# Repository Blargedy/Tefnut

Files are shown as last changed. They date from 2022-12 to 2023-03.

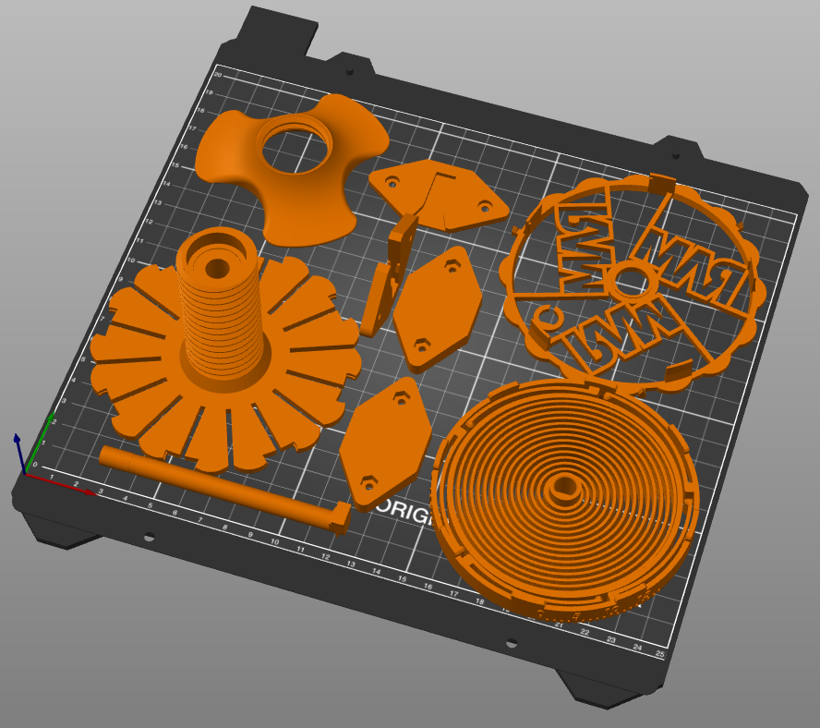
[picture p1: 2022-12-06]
Individual-Spool_Dry-box_Inserts_and_Modified_Universal_Auto-Rewind_Spool_Holder/images/ExampleLayoutOfRequiredParts.png

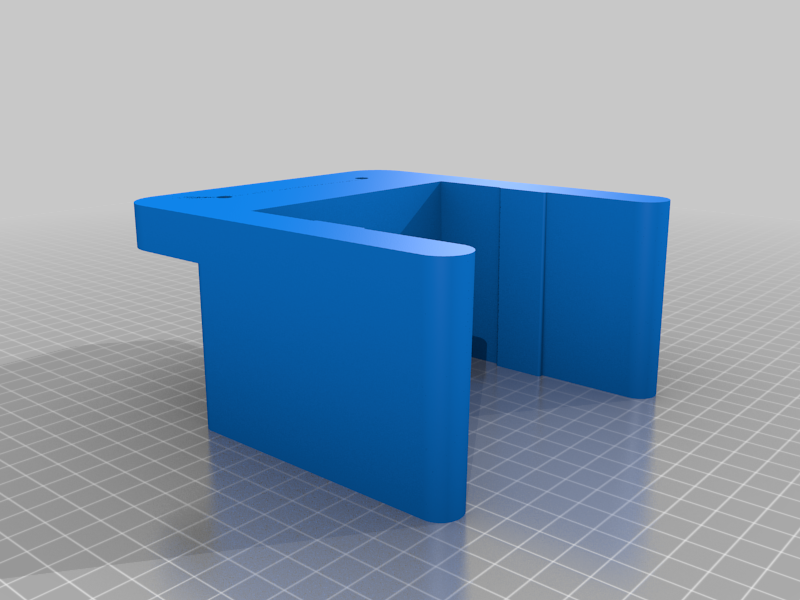
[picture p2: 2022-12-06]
Drybox_Holder_for_Rubbermaid_1861476_Zylar_Container/images/DryboxHolder_SlideDown_v1.2.png

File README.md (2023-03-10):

# Tefnut Filament Handling
A system for the management of 3D printer filament. Based on cereal containers as individual dryboxes for spools of filament.

## Goal
The primary purpose of Tefnut is to keep filament clean of dust/debris to avoid jams and clogs, and can also help with keeping filament dry. I found there is too much air leakage in the system to maintain a low humidity long term without regular swapping of large amounts of dessecant. That being said, with regular swapping of large amounts of dessecant it is possible to keep each filament completely dry. 

## [Individual-Spool Dry-box Inserts and Modified Universal Auto-Rewind Spool Holder](https://github.com/Blargedy/Tefnut_Filament_Handling/tree/main/Individual-Spool_Dry-box_Inserts_and_Modified_Universal_Auto-Rewind_Spool_Holder)

This set of modifications and new custom parts moves [VincentGroenhuis'](https://www.thingiverse.com/thing:3338467) rewinder into a Rubbermaid 1776473 21-Cup Dry Food Container. When combined with a panel mounted pneumatic fitment or mmu tube holder you can print directly from this dry-box.

## [The Filament Butler - a manual replacement of the prusa MMU2s](https://github.com/Blargedy/The_Filament_Butler)
cropped_20221014_140138
For use in high(ish) temperature printing, where the Prusa MMU2s electronics cannot function, this butler keeps the filaments handy for loading, all without needing to open the dryboxes. See the github site for The Filament Butler for instructions and files.

## [Drybox Holder for Rubbermaid 1861476 Zylar Container](https://github.com/Blargedy/Tefnut_Filament_Handling/tree/main/Drybox_Holder_for_Rubbermaid_1861476_Zylar_Container)

This slide-down box-holder keeps the dry-boxes in place during lid-lifting maintenance. 

## [6mm OD tubing to MMU2 adapter](https://github.com/Blargedy/Tefnut_Filament_Handling/tree/main/6mm_OD_Tubing_to_MMU_Adapter)

A similar push-to-connect interface for 6mm tubing as the pneumatic fitment tube holders, for connected the tubing to the MMU2.

## [Push-Fit Tube Holders For 6mm Outer Diameter Tubing](https://github.com/Blargedy/Tefnut_Filament_Handling/tree/main/Push-Fit_Tube_Holders_For_6mm_Outer_Diameter_Tubing)

A two-part mod; An attachment point for 6mm OD tubing on the outside, and a funnel guide for filament being pulled from spools that are almost out of filament on the inside.

## [Enclosure Lid Safety-Harness](https://github.com/Blargedy/Tefnut_Filament_Handling/tree/main/Enclosure_Lid_Safety-Harness)

An anchor point for the lid intended for a 2mm twisted steel cable to loop through and create an over-lifting protection.

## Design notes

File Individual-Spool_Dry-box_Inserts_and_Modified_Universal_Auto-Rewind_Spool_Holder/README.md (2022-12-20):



Need to move your spool of filament into a dry-box while still using the Universal Auto-Rewind Spool Holder? This set of files will let you do so. This set of modifications and new custom parts moves VincentGroenhuis' rewinder into a [Rubbermaid 1776473 21-Cup Dry Food Container](https://www.amazon.ca/Rubbermaid-1776473-21-Cup-Food-Container/dp/B003EYUZJU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). When combined with a panel mounted pneumatic fitment or mmu tube holder you can print directly from this dry-box. Use this [better axle](https://www.thingiverse.com/thing:4324181) remix made by [itnaanti](https://www.thingiverse.com/itnaanti/designs).

For keeping a set of dry-boxes on top of the [mmu compatible printing enclosure](https://blog.prusaprinters.org/mmu2s-printer-enclosure/) see the [dry-box holder](https://github.com/Blargedy/Tefnut/tree/main/Drybox_Holder_for_Rubbermaid_1861476_Zylar_Container), specifically designed for the Rubbermaid container used. Five of these holders are required, as well as 470 cm of new longer and wider tubing. The new tubing is 4mm inner diameter (ID) and 6mm outer diameter (OD), from now on called 4 ID/6 OD tubing.The lengths to cut are:

* 4x 90 cm
* 1x 110 cm

If you value symmetry over minimum tubing length you can use a 3-in-the-front-2-in-the-back pattern and cut a 90 cm piece to 110 cm instead. This will give a total tube length of 480 cm. 

### NB: due to the increased length of tubing required to use these containers on top of the printer enclosure, using the same 2 ID/4 OD tubing the mmu came with, but cut longer, will not work. The friction introduced is too high and will cause frequent jams, especially during filament unloads. 

This is due to the slight deformation of the filament by the bondtech gear during unload being too much if there is already friction from 90cm of tubing. Previously I used very short lengths of 4 ID/6 OD tubing, but the reverse torque of the rewinders pulled the filament out of ready-to-load position. Now however the 90cm of tubing is enough friction to prevent the rewinder pulling the filament out, but low enough to feed beautifully. I've had no load/unload issues since switching to the high diameter tubing. 

In order to use 4 ID/6 OD tubing you'll need a [push-to-fit PTFE holder](https://github.com/Blargedy/Tefnut/tree/main/Prusa_i3_Mk3s_MMU2s_6mm_OD_tubing_to_MMU_adapter) to replace the bracket at the back of the MMU. If you instead want to use PC6-M10 pneumatic fittings see the [source file](https://www.thingiverse.com/thing:3233579) I used to remix my version. The pneumatic connectors can be bought inexpensively from ebay, if you're willing to wait a couple months to get them. The tubing can be bought most easily from [McMaster-Carr](https://www.mcmaster.com/3295n6) at $0.55USD/foot

A further issue that may arise due to usage of these dry boxes is a back heavy enclosure lid. If you are careful it is not an issue, but it may happen that when you open the lid too far it flips past the axis of rotation to the other side and crashes all of the dryboxes to the ground and breaks the hinges. However fear not, I have experienced this failure on your behalf, and designed a [part](https://github.com/Blargedy/Tefnut/tree/main/MMU-Compatible_Enclosure_Lid_Safety-Harness_Upper_Lid_Bracket) to prevent this from happening to you. 

The tube holders at the top of each dry-box are found [here](https://github.com/Blargedy/Tefnut/tree/main/Push-Fit_Tube_Holders_For_6mm_Outer_Diameter_Tubing_and_Anti-Seizing_Filament_Guide_for_Filament_in_Individual-Spool_Dry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)

#### Change log
#### v1.1 Sept 16 2019
* remove square boss on both sides
* thin roundEndAxleHolder container-side wall by 1mm
* thin roundEndAxleHolder inside-facing wall by 1mm

#### v1.2 Sept 18 2019
* deepen counter-bore for bolts to avoid snagging on auto-rewind dial
* thin holders to make space for larger spools

#### v1.2 Nov 1 2019
* tighten hex nut counter-bore to prevent spinning of nut. Previous nut version was v1.1
* Add 3mf export from solidworks

Use PETG if at all possible, as the parts are quite small and need to be functional strength.

NB: the parts are very thin, so wait until they are completely cooled off before removing them from the bed, or risk warping them. 

Print the inserts lying flat, except for the slotted insert, which should be printed with the opening facing up with supports under the slope if you so desire. Use the provided 3mf file to get an example selection and layout which can be modified.

Warning: the spring is very difficult to get to stay on the plate and not ruin a print. I therefore recommend printing it separately so it doesn't ruin a 16h print with its 4-5 retries before the plate is sticky enough to have it succeed. 

## Parts to Print

### From Original
* Curved nut (regular or XL)
* Spring flat
* Dial
* Clutch
* Clip

### From This Set
* One of each STL in the base folder
* One extra Axle Holder Nut

ExampleLayoutOfRequiredParts

Example layout containing all the required parts. See provided 3mf file to get all parts already laid out.

#### Tips for installation
* Mark or make note of the end from which you measured the 110mm as the location will be off by 5mm if you don't use the same edge when marking the holes for the other sides' holders. 
* Drill on low speed or you might crack the plastic. 
* Use a razor scraper to trim off the drill burs.
* Use socket head M3x10 spare bolts from the prusa kit, and the corresponding hex nuts to attach the inserts. 
* Use only a single curved nut to attach the spool onto the rewinder hub. 
* For v1.01 springs make sure the spring/clutch/dial assembly is on the right side, looking at the back of the dry-box.
* Assemble the rewinder using the instructions from the original rewinder by VincentGroenhuis.



Dimensions for drilling the four required holes into the container

# Instructions
## Drybox
1. Drill the holes in the measured locations shown in the picture above.
2. Using the same drill bit, pre-drill the holes of the four insert pieces to allow the bolts to pass easier.
3. Put two M3x10 bolts into the holes of the slotted end axle holder's two holes, pushing them most or all of the way through.
4. Reach inside the container and, making sure the open end of the U shaped holder is facing towards the opening of the container, push the two bolts out through the holes of the dry-box. Pushing the bolts through as far as possible makes the next step easier. 
5. Keeping one hand inside the container with fingers on the bolts, turn the container onto it's side with the bolt-protruding side facing up.
6. Place one axle holder nut over the protruding bolts and push the bolts up through the holes as much as possible.
7. Place two hex nuts into the hexagonal counter-bores on the two holes. 
8. If possible, turn the bolts with your fingers to get at least one rotation of purchase on the threads of the nut.
9. Using a 2.5mm hex key (if you used the prusa spare hardware), tighten the bolts evenly until they are fully tight. The head of the bolt should sink into the counter-bore with a little bit of the top poking out. 
10. Repeat steps 3-9 with the round end axle holder and remaining axle holder. The bolts will sink further into the part than the surface of the part. 
11. Install your preferred panel-mounted tube feed-through, and insert one of the PTFE tubes from the MMU into it. 
12. Lower the assembled spool holder and spool contraption into the dry-box. If you are using the v1.01 spring, put the spring side on the right when looking from behind, with the spool delivering filament from the top of the spool. The spring should be on the left if the spool is delivering filament from the bottom of the spool. 
13. If desired, put desiccant into the bottom of the dry-box, close the lid and you're rockin'.

## Tubing



The problem that arises by switching to larger tubing is that the 1.75mm filament gets stuck  on the lip of the mmu right before the bondtech gears. There are fancy adapters you can buy or print, but no need, this way works better, doesn't need new hardware, and works with the stock mmu tube holder, my 6mm OD [push to fit plate](https://www.thingiverse.com/thing:3812486), or PC6-M10 connector plates. In the pictures I used my push to fit plate. 

It is recommended to first install the [drybox holders](https://github.com/Blargedy/Tefnut/tree/main/Drybox_Holder_for_Rubbermaid_1861476_Zylar_Container) before installing these tubes.

1. Install the mmu tube-holding plate of your choice.
2. Cut the 4 ID/6 OD tubing to length, either 4x90cm & 1x110cm, or 3x90cm & 2x110cm. 
3. Mark out five dots on the back acrylic panel: 28cm up from the bottom edge, 2cm apart, centered on the panel.
4. Using a sharp 8mm drill bit, drill the five spots you marked. 8mm is enough to give friction so things don't wobble around, but leaves enough play to attach the tubes and move the printer.
5. Insert the 4 ID/6 OD tubing through the holes, and hook the other end of the tube into the empty dry-box holder. The stiffness of the tubing will hold it in place until you attach the tubing to the drybox. Make sure to put the 110cm long length(s) of tubing in the correct hole corresponding to the further back drybox holder(s).
6. Push the tubing as far as it will go. 
7. Attach the dryboxes to the enclosure lid, and connect each tube to its box. 

## Loading Procedure
1. Disconnect the tube at the MMU side.
2. Attach the rewinder to the spool of filament, spring on the right side when looking from the front of the printer, keyed end of the axel on the spring side.
3. Mount the axle onto the inserts.
4. Feed filament down the tube until it extends out of the other end.
5. Attach the lid to the container.
6. Using the screen of the prusa, begin loading filament
7. Feed the filament into the MMU until it grips the filament.
8. Attach the tube to the back of the MMU.

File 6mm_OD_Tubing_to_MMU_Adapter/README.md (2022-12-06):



In order to lower friction in the path of the filament loading to the MMU, I am stepping up the size of the tubes from 4 mm to 6 mm outer diameters. I was not able to find PC6-M10*1 pneumatic fittings, which would normally be used to fit 6mm tubing to the adapter vertigo235 designed, for a reasonable price. This is to give a similar push-to-connect interface for 6mm tubing as the pneumatic ones. It won't be air tight, but it is tight enough to feed the filament in correctly. An added bonus is that you can fit the tubes in one at a time instead of the juggling act of all at once like with the stock mmu.

STL file is called "OD6mmTubeToMMU_Adapter.STL". I left the original part in the folder in case you want to continue my edit in solidworks.

OD6mmTubeToMMU_Adapter

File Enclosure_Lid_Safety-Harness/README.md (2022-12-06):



The lifting lid of the MMU compatible prusa [enclosure](https://blog.prusaprinters.org/mmu2s-printer-enclosure/) becomes very back heavy when five of my [dryboxes](https://github.com/Blargedy/Tefnut/tree/main/Individual-Spool_Dry-box_Inserts_and_Modified_Universal_Auto-Rewind_Spool_Holder) are on top. While servicing the printer I pushed the lid up too high and it flipped all the way back on itself, destroying the hinges, and several of my rewinders and tube adapters. In order to avoid this happening again I designed an anchor point for the lid intended for a 2mm twisted steel cable to loop through and create an over-lifting protection. I imagine it would also work with nylon cords or twine if they are thin enough. 

The anchor is designed to use a large area of contact on the top of the lid as attachment to the lid, since a screwed plate to the inside of the lid would rip out in a full force flip. The large plate also serves as a cover for any imperfections in cuts to the top of the enclosure. 

Print in the following orientation: 

PrintingOrientation_v1 1

SW_Part_v1 1





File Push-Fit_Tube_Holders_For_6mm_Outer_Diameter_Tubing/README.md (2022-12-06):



These pieces are designed to be used with my individual-spool drybox inserts. The outer fitment is a panel mounted push-fit holder for 6mm outer diameter tubing, and the inside fitment is a funnel guide for filament being pulled from spools that are almost out of filament
2021-07-27_21_03_01-Autodesk_Fusion_360
2021-07-27_21_03_31-Autodesk_Fusion_360

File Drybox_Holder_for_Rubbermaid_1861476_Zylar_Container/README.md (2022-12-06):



Need to keep your spools dry and clean, but the folding lid of the [mmu compatible printer enclosure](https://blog.prusa3d.com/mmu2s-printer-enclosure_30215/) drops your dry-box to the ground? This slide-down box-holder keeps the dry-box in place during lid-lifting maintenance. This holder was designed for [this](https://www.amazon.ca/dp/B00BEUDWIC/ref=cm_sw_em_r_mt_dp_U_cDVBDbEDKND4F?tag=1) cereal box by Rubbermaid, which can be used as an individual-roll dry-box.



PartTopView

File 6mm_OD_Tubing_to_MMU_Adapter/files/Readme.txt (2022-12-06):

This is to guide 6mm outer diameter/4mm inner diameter tubing into the MMU, without the need for expensive pneumatic adapters.

The original file is included for reference, and in case SW complains it needs the reference step file.
Finished part is called "mmu2-rear-PTFE-holder(M1).sldprt", and the exported STL file is called "OD6mmTubeToMMU_Adapter.STL".

Prints well in PETG.

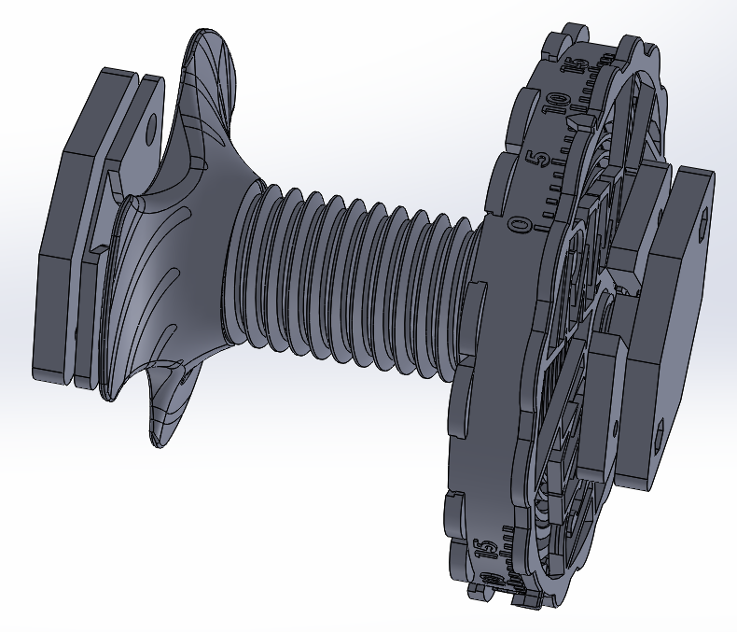
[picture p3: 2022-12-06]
Individual-Spool_Dry-box_Inserts_and_Modified_Universal_Auto-Rewind_Spool_Holder/images/RewinderOnAxleAndHolder.png

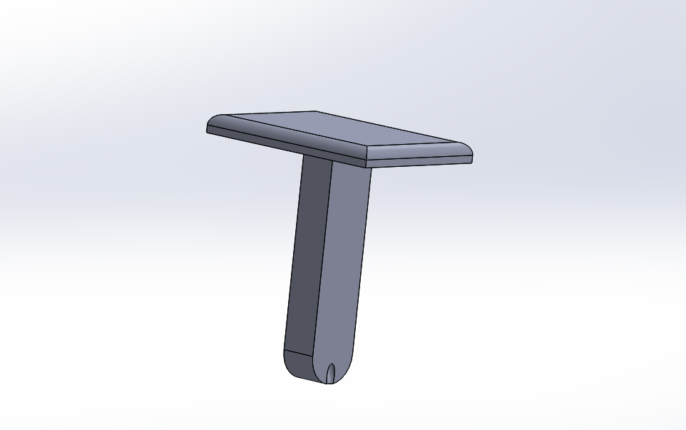
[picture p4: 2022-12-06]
Enclosure_Lid_Safety-Harness/images/SW_Part_v1.1.png

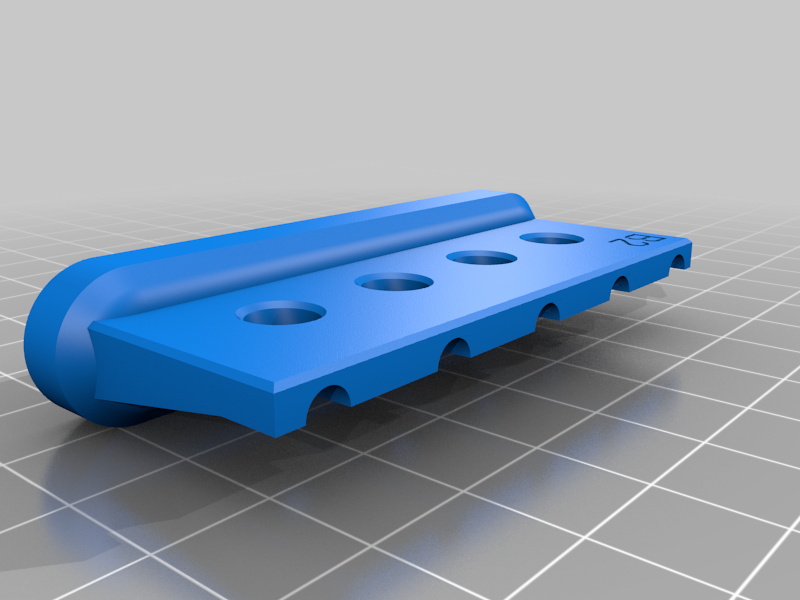
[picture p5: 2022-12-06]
6mm_OD_Tubing_to_MMU_Adapter/images/OD6mmTubeToMMU_Adapter.png

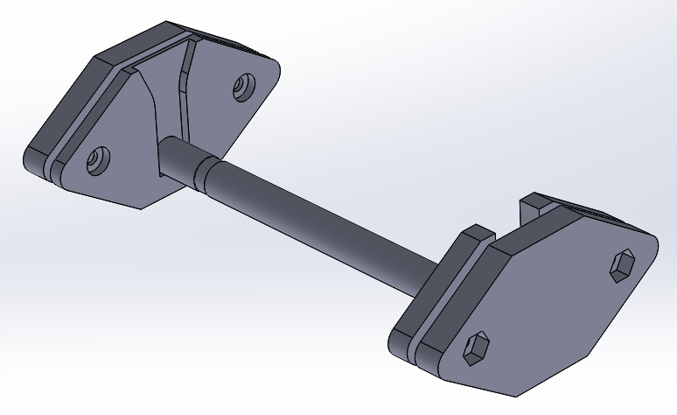
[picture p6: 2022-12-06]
Individual-Spool_Dry-box_Inserts_and_Modified_Universal_Auto-Rewind_Spool_Holder/images/AxleAndHolderShowingRoundEnd.png

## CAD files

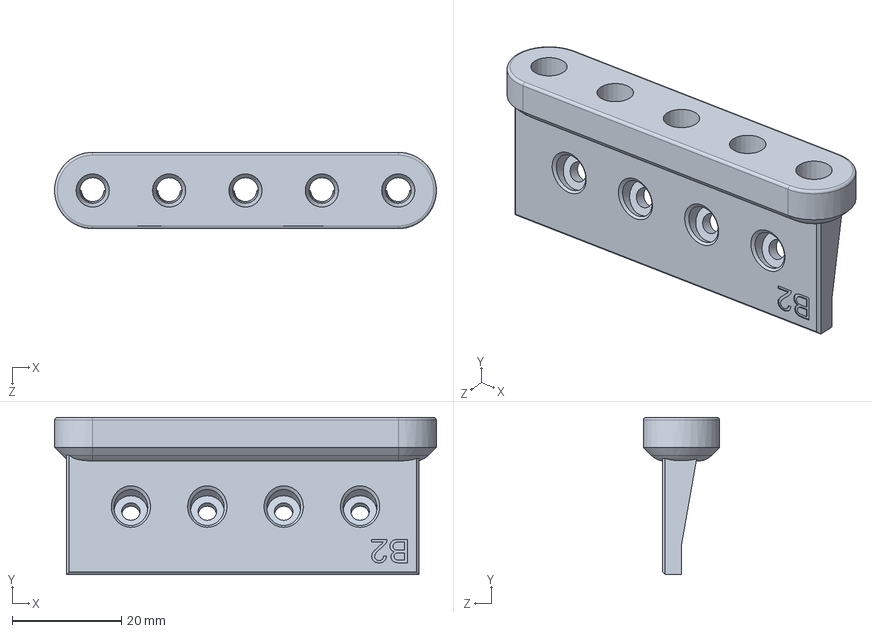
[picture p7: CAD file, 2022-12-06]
6mm_OD_Tubing_to_MMU_Adapter/files/mmu2-rear-PTFE-holderM1.sldprt
70.0 x 28.8 x 14.0 mm

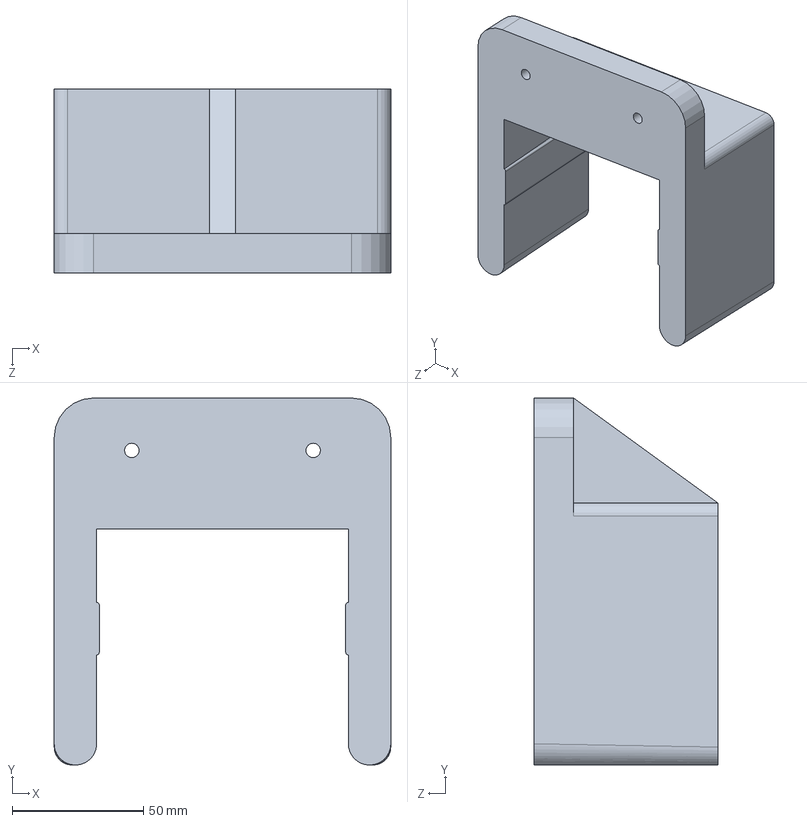
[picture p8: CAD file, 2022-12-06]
Drybox_Holder_for_Rubbermaid_1861476_Zylar_Container/files/DryboxHolder_SlideDown_v1.2.SLDPRT
128.4 x 140.0 x 70.0 mm

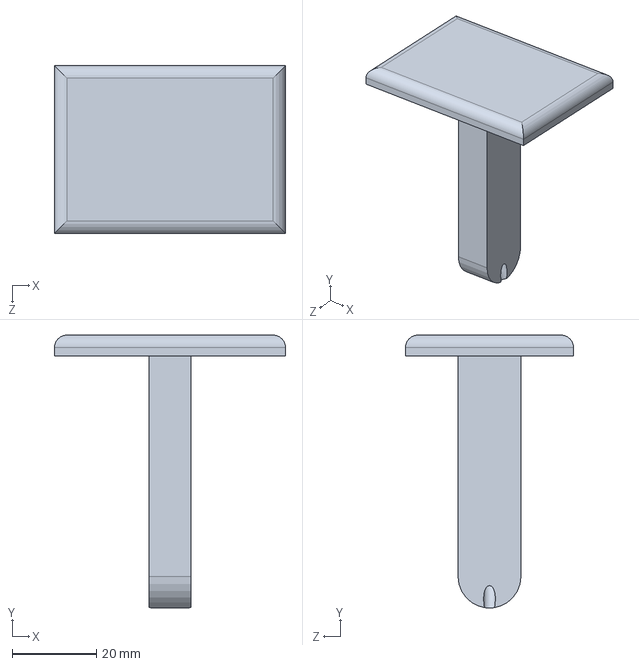
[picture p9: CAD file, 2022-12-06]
Enclosure_Lid_Safety-Harness/files/LidHarness.SLDPRT
55.0 x 65.0 x 40.0 mm

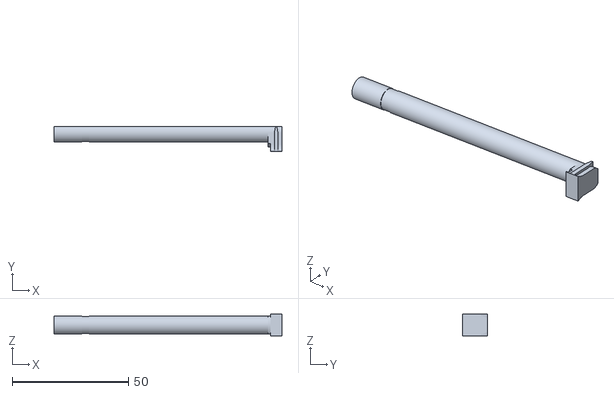
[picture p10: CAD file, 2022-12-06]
Individual-Spool_Dry-box_Inserts_and_Modified_Universal_Auto-Rewind_Spool_Holder/files/ToMakeThingiverseHappy.STL
98.0 x 10.7 x 9.40

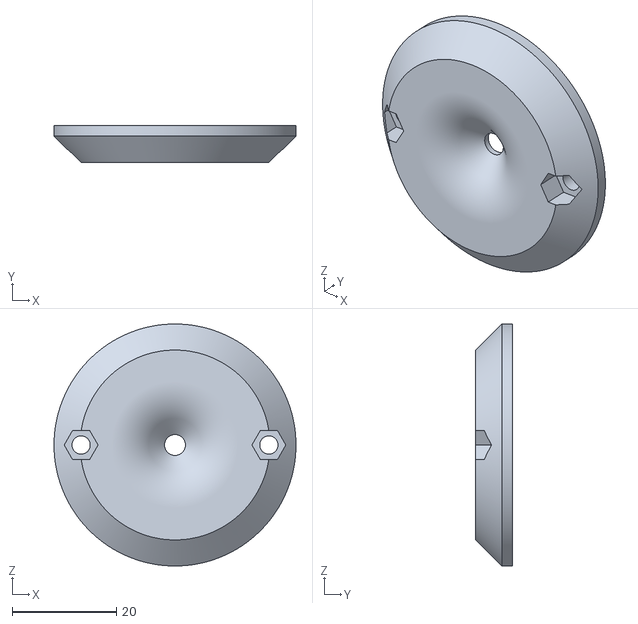
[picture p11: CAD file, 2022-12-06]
Push-Fit_Tube_Holders_For_6mm_Outer_Diameter_Tubing/files/InsideFitment.stl
46.4 x 7.00 x 46.4

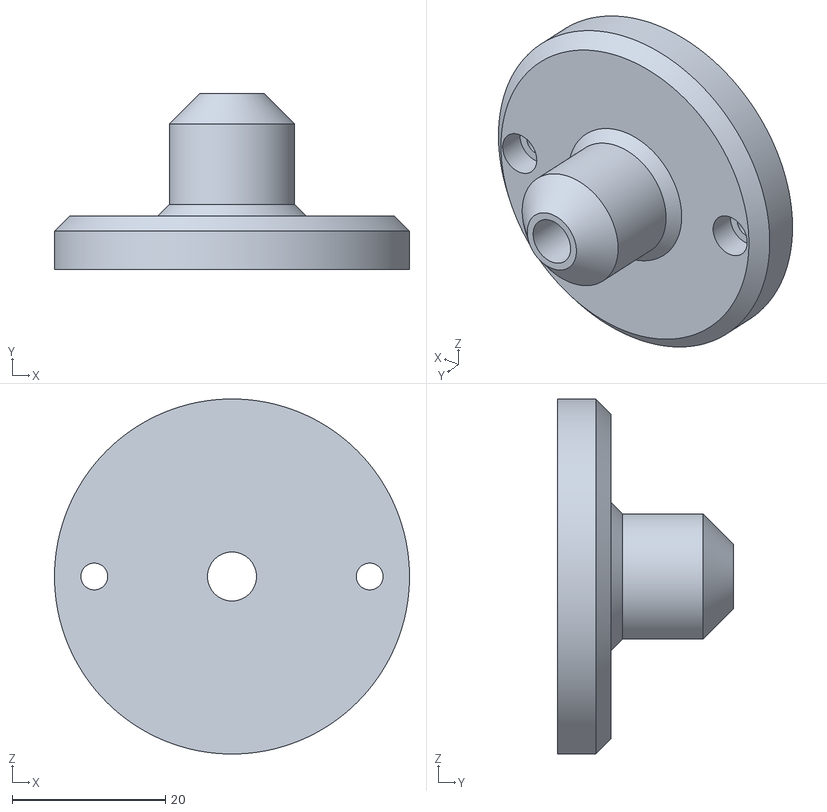
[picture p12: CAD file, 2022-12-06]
Push-Fit_Tube_Holders_For_6mm_Outer_Diameter_Tubing/files/OutsideFitment.stl
46.4 x 23.0 x 46.4

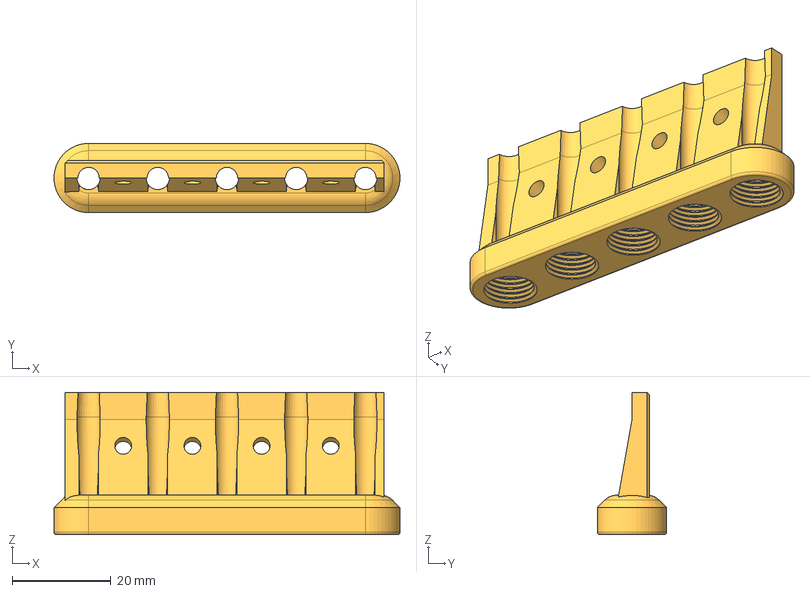
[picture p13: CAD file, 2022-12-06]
6mm_OD_Tubing_to_MMU_Adapter/files/M10PassthroughPlate.stp
70.0 x 14.0 x 28.8 mm

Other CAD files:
6mm_OD_Tubing_to_MMU_Adapter/files/OD6mmTubeToMMU_Adapter.STEP
Drybox_Holder_for_Rubbermaid_1861476_Zylar_Container/files/DryboxHolder_SlideDown_v1.2.STL
Push-Fit_Tube_Holders_For_6mm_Outer_Diameter_Tubing/files/Tube_fitments.f3d

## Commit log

2022-12-06 initial migration
    [DryboxHolder_SlideDown_v1.2.SLDPRT, DryboxHolder_SlideDown_v1.2.STL, InsideFitment.stl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]
2022-12-06 change folder names
    [InsideFitment.stl, LidHarness.SLDPRT, M10PassthroughPlate.stp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]
